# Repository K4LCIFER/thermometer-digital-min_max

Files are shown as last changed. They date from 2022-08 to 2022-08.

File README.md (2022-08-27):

# Digital Min/Max Thermometer

# Introduction

The following project holds all the required files, and information to build a
battery powered digital min/max thermometer.

## Scope

The project is intended to be simple, reliable, and cheap.

## Directory Guide

- [Electronics (PCB, etc.)](./electronics)
- [Hardware (Case, etc.)](./hardware)
- [Firmware](./firmware)

## Donations

Monero (XMR): `8BG1wFgq4fTKhekEh58Ae1M1ShGUsp15yFXJUuCXYQiFKUmDuQ9BK8tTfUfvXV2WR1CPE5Ry6DY45DmdDQm3SiCY7Jkw5ws`
<details><summary>Click to show XMR QR-Code</summary>
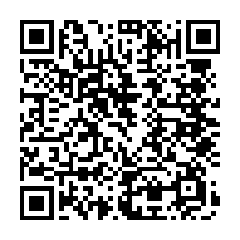
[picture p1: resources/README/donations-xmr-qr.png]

</details>

Bitcoin (BTC): `bc1qvx8jt2qxar7thnxczqalzeyspd0xz8xr046edu`
<details><summary>Click to show BTC QR-Code</summary>
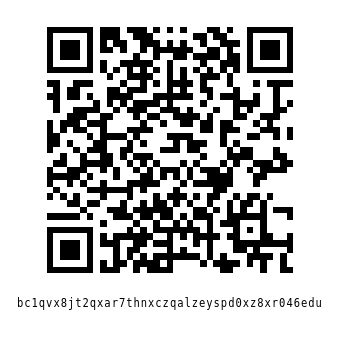
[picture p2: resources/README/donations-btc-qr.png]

</details>

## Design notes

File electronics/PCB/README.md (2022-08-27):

# PCB

## Introduction

This is the directory for the main PCB for the digital min/max thermometer. 

## Directory Map

- [Reference, and manufacturing/assembly information](./resources)
- [Gerber files](./gerbers)
- [PCB Schematic PDFs](./schematics)
- [Files relating to the design software](./project-files)

## Images

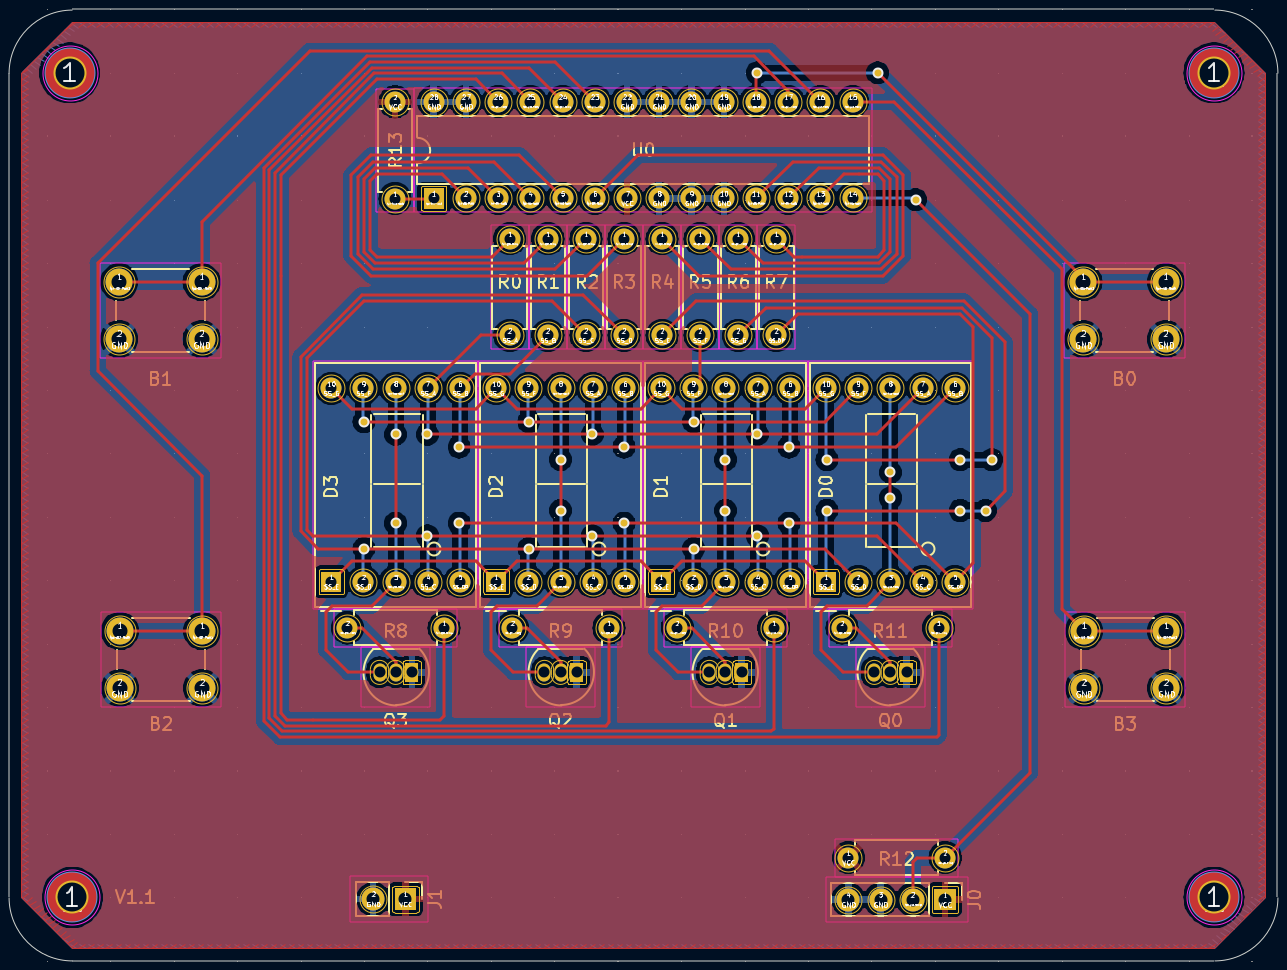
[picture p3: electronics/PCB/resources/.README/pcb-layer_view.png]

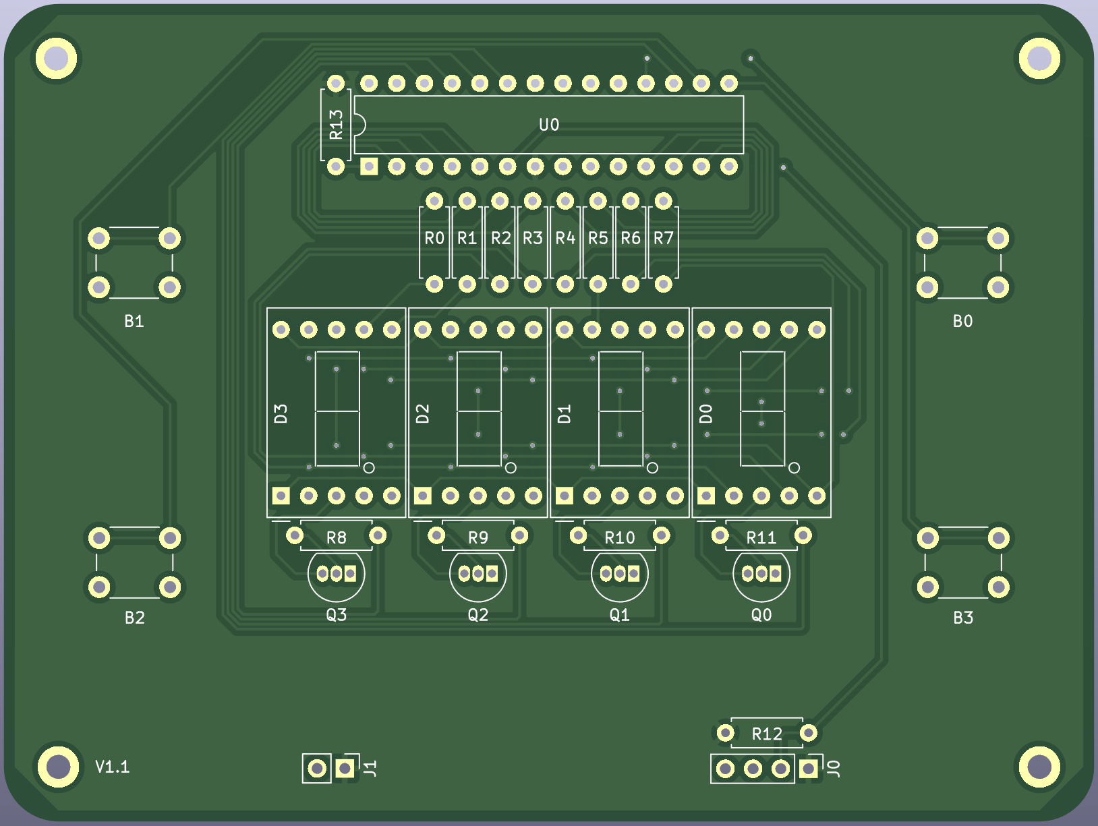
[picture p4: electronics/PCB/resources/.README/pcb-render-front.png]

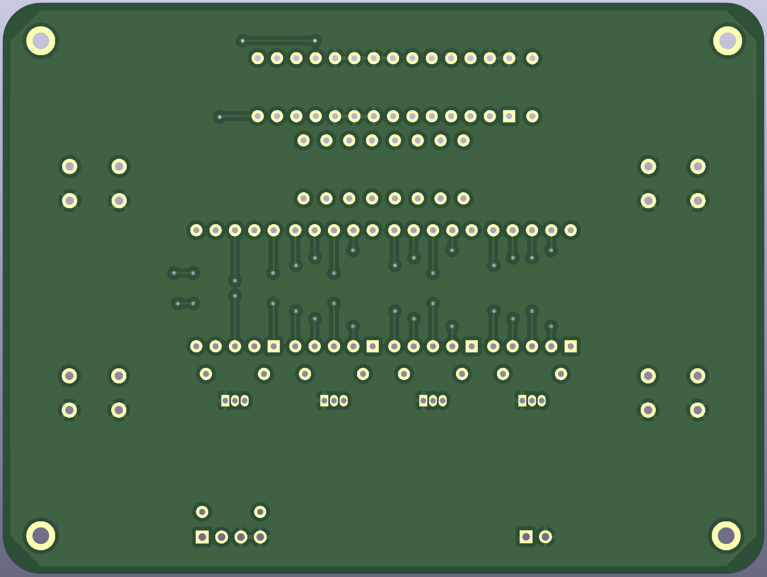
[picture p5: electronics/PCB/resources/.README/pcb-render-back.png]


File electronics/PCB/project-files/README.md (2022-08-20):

This PCB is designed with [KiCAD](https://www.kicad.org/) v6.0.7

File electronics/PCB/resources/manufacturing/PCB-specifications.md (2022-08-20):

# PCB Specifications

These are the physical specifications used for the manufacturing of the PCB.

- Layers: 2
- PCB Thickness:

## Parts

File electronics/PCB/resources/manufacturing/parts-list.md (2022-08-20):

# Parts List
| Part Name | Quantity | Notes |
|---|---|---|
| ATmega328P-U | 1 | | 
| 100R, 0.25W, 1% | 8 | Generic | 
| 10kR, 0.25W, 1% | 1 | Generic |
| 4.7kR, 0.25W, 1% | 1 | Generic |
| 680R, 0.25W, 1% | 4 | Generic |
| INND-TS56RCB | 4 | |
| PN2222A | 4 | |
| 2-Pin Male Header | 1 | Generic |
| 4-Pin Male Header | 1 | Generic |
| 6mm x 6mm Tactile Button | 4 | Generic |

Note: See [this](../datasheets) directory for datasheets on the above components.

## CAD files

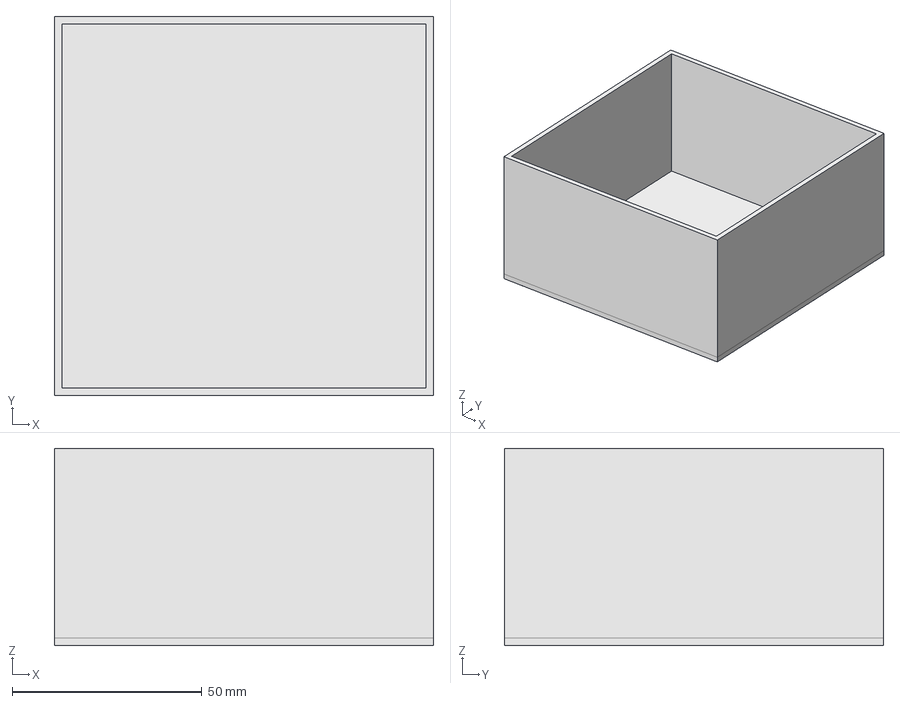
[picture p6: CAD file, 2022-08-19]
hardware/case/project-files/bottom.FCStd
100.0 x 100.0 x 52.0 mm

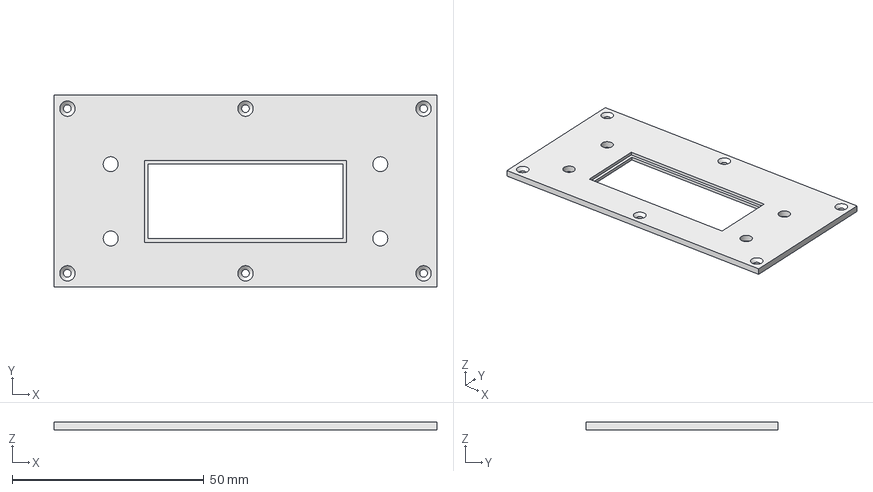
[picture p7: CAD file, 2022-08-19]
hardware/case/project-files/top.FCStd
100.0 x 50.0 x 2.00 mm

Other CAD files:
hardware/case/project-files/global_params.FCStd

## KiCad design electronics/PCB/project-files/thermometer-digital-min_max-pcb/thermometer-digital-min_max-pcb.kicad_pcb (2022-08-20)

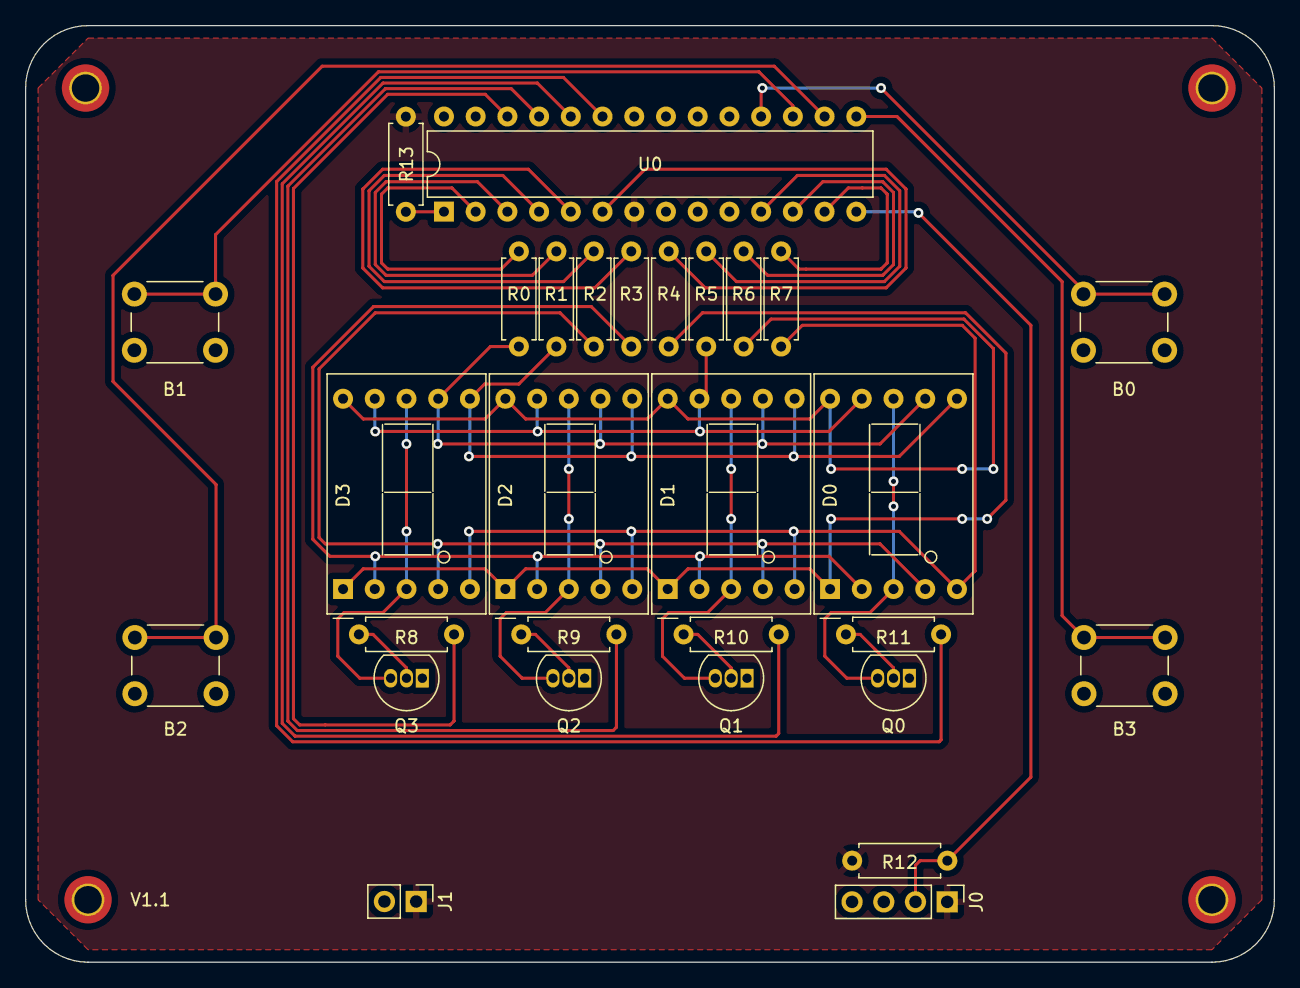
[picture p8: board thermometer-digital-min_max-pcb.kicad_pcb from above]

Board: 2 copper layers, 100.0 x 75.0 mm, 29 parts (0 on the bottom side), 36 nets.

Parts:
B0: disp_current_temp; SW_PUSH_6mm_H9.5mm
B1: disp_max_temp; SW_PUSH_6mm_H9.5mm
B2: disp_min_temp; SW_PUSH_6mm_H9.5mm
B3: reset_saved_temps; SW_PUSH_6mm_H9.5mm
D0, D1, D2, D3: INND-TS56; D1X8K
J0: sensor_connection; PinHeader_1x04_P2.54mm_Vertical
J1: battery_connection; PinHeader_1x02_P2.54mm_Vertical
Q0, Q1, Q2, Q3: PN2222A; TO-92_Inline
R0, R1, R2, R3, R4, R5, R6, R7: 100R; R_Axial_DIN0207_L6.3mm_D2.5mm_P7.62mm_Horizontal
R8, R9, R10, R11: 680R; R_Axial_DIN0207_L6.3mm_D2.5mm_P7.62mm_Horizontal
R12: 4.7k; R_Axial_DIN0207_L6.3mm_D2.5mm_P7.62mm_Horizontal
R13: 10k; R_Axial_DIN0207_L6.3mm_D2.5mm_P7.62mm_Horizontal
U0: ATmega328P-U; DIP-28_W7.62mm

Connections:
/SS_A: D0.7 (A), D1.7 (A), D2.7 (A), D3.7 (A), R0.2
/SS_B: D0.6 (B), D1.6 (B), D2.6 (B), D3.6 (B), R1.2
/SS_C: D0.4 (C), D1.4 (C), D2.4 (C), D3.4 (C), R2.2
/SS_D: D0.2 (D), D1.2 (D), D2.2 (D), D3.2 (D), R3.2
/SS_DP: D0.5 (DP), D1.5 (DP), D2.5 (DP), D3.5 (DP), R7.2
/SS_E: D0.1 (E), D1.1 (E), D2.1 (E), D3.1 (E), R4.2
/SS_F: D0.9 (F), D1.9 (F), D2.9 (F), D3.9 (F), R5.2
/SS_G: D0.10 (G), D1.10 (G), D2.10 (G), D3.10 (G), R6.2
GND: B0.2, B1.2, B2.2, B3.2, J0.3, J0.4, J1.2, Q0.1 (E), Q1.1 (E), Q2.1 (E), Q3.1 (E), U0.8 (GND), U0.9 (XTAL1/PB6), U0.10 (XTAL2/PB7), U0.19 (PB5), U0.20 (AVCC), U0.21 (AREF), U0.22 (GND), U0.27 (PC4), U0.28 (PC5)
unnamed: B0.1, U0.18 (PB4)
unnamed: B1.1, U0.17 (PB3)
unnamed: B2.1, U0.16 (PB2)
unnamed: B3.1, U0.15 (PB1)
unnamed: D0.3 (CC), D0.8 (CC), Q0.3 (C)
unnamed: D1.3 (CC), D1.8 (CC), Q1.3 (C)
unnamed: D2.3 (CC), D2.8 (CC), Q2.3 (C)
unnamed: D3.3 (CC), D3.8 (CC), Q3.3 (C)
unnamed: J0.2, R12.2, U0.14 (PB0)
unnamed: Q0.2 (B), R11.2
unnamed: Q1.2 (B), R10.2
unnamed: Q2.2 (B), R9.2
unnamed: Q3.2 (B), R8.2
unnamed: R0.1, U0.2 (PD0)
unnamed: R1.1, U0.3 (PD1)
unnamed: R2.1, U0.4 (PD2)
unnamed: R3.1, U0.5 (PD3)
unnamed: R4.1, U0.6 (PD4)
unnamed: R5.1, U0.11 (PD5)
unnamed: R6.1, U0.12 (PD6)
unnamed: R7.1, U0.13 (PD7)
unnamed: R8.1, U0.26 (PC3)
unnamed: R9.1, U0.25 (PC2)
unnamed: R10.1, U0.24 (PC1)
unnamed: R11.1, U0.23 (PC0)
unnamed: R13.1, U0.1 (~RESET/PC6)
VCC: J0.1, J1.1, R12.1, R13.2, U0.7 (VCC)

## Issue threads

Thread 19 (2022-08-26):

The mounting hole in the top left corner of the PCB is slightly out of allignment

K4LCIFER, 2022-08-26:
The center of the mounting hole is 4.8mm from the side, and off centered from the top at 87.7deg; It should be 5mm and 90deg for both.

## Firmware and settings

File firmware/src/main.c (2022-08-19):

#define INND_TS56

/* System Defines */
#define F_CPU 8000000UL

/* AVR Includes */
#include <avr/io.h>
#include <avr/interrupt.h>
#include <util/delay.h>
#include <avr/sleep.h>
/* GCC Includes */
#include <string.h>
#include <math.h>
#include <stdlib.h>
/* Library Includes */
#include "seven_segment.h"
#include "atmega328p_utils.h"
/* Program Includes */
#include "am2302_utils.h"
#include "pins.h"
#include "display.h"

// NOTE: Doesn't have to be global, but its currently like this for debugging purposes.
uint16_t temp_data; 

volatile uint16_t ovf_counter = 0;

volatile int current_temp;
volatile int max_temp;
volatile int min_temp;


// NOTE: Should probably disable button interrupts when the sensor is receiving
// to prevent interruption. Don't clear the flag, however, so when they get
// reeneabled, their ISR gets immediately called.
void init(void);
uint8_t get_temp(void);
void display_temp(uint16_t temp_data);
void process_buttons(void);

void main(void)
{
    init();
    // Clear the Timer 2 OVF interrupt flag.
    TIFR2 |= (1 << TOV2);
    // Enable the Timer 2 OVF interrupt.
    TIMSK2 |= (1 << TOIE2);
    // Start Timer 2 with CLK/1024.
    TCCR2B |= ((1 << CS22) | (1 << CS21) | (1 << CS20));
    while(1)
    {
        if (ovf_counter >= 100)
        {
            PCICR &= ~(1 << PCIE0); // Disable pushbutton interrupts.
            ovf_counter = 0;
            get_temp();
            if (current_temp > max_temp)
            {
                max_temp = current_temp;
            }
            if (current_temp < min_temp)
            {
                min_temp = current_temp;
            }
            PCICR |= (1 << PCIE0); // Enable pushbutton interrupts.
        }
    }
}

void init(void)
{

    // Reduce power consumption:
    PRR |= (1 << PRADC);    // Disables the ADC.
    PRR |= (1 << PRUSART0); // Disables the USART0
    PRR |= (1 << PRSPI);    // Disables the SPI
/*     PRR |= (1 << PRTIM0);   // Disables the Timer0 */
    PRR |= (1 << PRTWI);    // Disables the TWI
    SMCR |= ((1 << SM1) | (1 << SM0));  // Power save mode
    SMCR |= (1 << SE);  // Enable sleep.
    sleep_bod_disable();    // Disable BOD.

    // Configure the buttons:
    // Set the button pins as inputs, and enable their pull-ups:
    // Reset saved temperatures button.
    pin_config_input(reset_saved_temps_btn_pin);
    pin_pullup_enable(reset_saved_temps_btn_pin);
    // Display minimum temperature button.
    pin_config_input(disp_min_temp_btn_pin);
    pin_pullup_enable(disp_min_temp_btn_pin);
    // Display maximum temperature button.
    pin_config_input(disp_max_temp_btn_pin);
    pin_pullup_enable(disp_max_temp_btn_pin);
    // Display current temperature button.
    pin_config_input(disp_current_temp_btn_pin);
    pin_pullup_enable(disp_current_temp_btn_pin);

    sensor_init();
    display_init();


    sei();  // Enable global interrupts.

    // Initialize values:
    get_temp();
    max_temp = current_temp;
    min_temp = current_temp;

    // Set up the interrupts for hte buttons:
    // Enable interrupts for the 4 pushbuttons on their respective pins.
    PCMSK0 |= ((1 << PCINT1) | (1 << PCINT2) | (1 << PCINT3) | (1 << PCINT4));
    PCIFR |= (1 << PCIF0); // Ensure that the button interrupt is cleared.
    PCICR |= (1 << PCIE0); // Enable pushbutton interrupts.

    DDRB |= (1 << DDB7); // Test LED.
}


uint8_t get_temp(void)
{
    sensor_rx(sensor_data_pin);    // Retreive data from the sensor.
    
    // Extract the temperature digits.
    /*uint16_t*/ temp_data = (raw_sensor_data & TEMP_DATA_BITMASK) 
        >> TEMP_DATA_OFFSET;
    current_temp = 1;   // Allows for easy multiplication.
    
    // Check if there if the negative temperature flag is set:
    if (raw_sensor_data & NEG_TEMP_BITMASK)
    {
        current_temp *= -1; // Floating point value of the temperature.
    }
    // Udate the current temperature value.
    current_temp *= temp_data;
    
    return 0;
}

// TODO: Add the a timer overflow catcher in case of a failed transmission.

// ISR for buttons:
ISR (PCINT0_vect)
{
    // Stop the temperature retreival timer.
    TCCR2B &= ~((1 << CS22) | (1 << CS21) | (1 << CS20));
    if (!pin_get_input_value(disp_current_temp_btn_pin))
    {
        if (current_temp < 0)
        {
            display_buffer[0] = SS_NEG;
        }
        for (uint8_t i = 0; i < 3; i++)
        {
            // Extract the digit.
            display_buffer[i] = ss_display_table[
                abs(current_temp / (int)pow(10,i)) % 10
            ];
        }
        display_buffer[1] |= SS_DEC;
        // Enable the display
        display_enable();
        // Reset the timer.
        TCNT1 = 0;
        // Clear the compare match A interrupt flag.
        TIFR1 |= (1 << OCF1A);
        // Interrupt on compare match.
        TIMSK1 |= (1 << OCIE1A);
        // Compare match at 5s (~39063 cycles)
        OCR1A = 39063; // 5s * (8MHz / 1024)
        // Enable the timer with CLK/1024
        TCCR1B |= ((1 << CS12) | (1 << CS10));
    }
    else if (!pin_get_input_value(disp_max_temp_btn_pin))
    {
        if (max_temp < 0)
        {
            display_buffer[0] = SS_NEG;
        }
        for (uint8_t i = 0; i < 3; i++)
        {
            // Extract the digit.
            display_buffer[i] = ss_display_table[
                abs(max_temp / (int)pow(10,i)) % 10
            ];
        }
        display_buffer[1] |= SS_DEC;
        // Enable the display
        display_enable();
        // Reset the timer.
        TCNT1 = 0;
        // Clear the compare match A interrupt flag.
        TIFR1 |= (1 << OCF1A);
        // Interrupt on compare match.
        TIMSK1 |= (1 << OCIE1A);
        // Compare match at 5s (~39063 cycles)
        OCR1A = 39063; // 5s * (8MHz / 1024)
        // Enable the timer with CLK/1024
        TCCR1B |= ((1 << CS12) | (1 << CS10));
    }
    else if (!pin_get_input_value(disp_min_temp_btn_pin))
    {
        if (min_temp < 0)
        {
            display_buffer[0] = SS_NEG;
        }
        for (uint8_t i = 0; i < 3; i++)
        {
            // Extract the digit.
            display_buffer[i] = ss_display_table[
                abs(min_temp / (int)pow(10,i)) % 10
            ];
        }
        display_buffer[1] |= SS_DEC;
        // Enable the display
        display_enable();
        // Reset the timer.
        TCNT1 = 0;
        // Clear the compare match A interrupt flag.
        TIFR1 |= (1 << OCF1A);
        // Interrupt on compare match.
        TIMSK1 |= (1 << OCIE1A);
        // Compare match at 5s (~39063 cycles)
        OCR1A = 39063; // 5s * (8MHz / 1024)
        // Enable the timer with CLK/1024
        TCCR1B |= ((1 << CS12) | (1 << CS10));
    }
    else if (!pin_get_input_value(reset_saved_temps_btn_pin))
    {
        max_temp = current_temp;
        min_temp = current_temp;
    }
}

// Display timeout ISR. (Turns off the display after 5s).
ISR (TIMER1_COMPA_vect)
{
    // Turn off the display.
    display_disable();
    // Stop the timer.
    TCCR1B &= ~((1 << CS12) | (1 << CS11) | (1 << CS10));
    // Disable the timer interrupts.
    TIMSK1 &= ~(1 << OCIE1A);
    // Restart the temperature retreival timer.
    TCCR2B |= ((1 << CS22) | (1 << CS21) | (1 << CS20));
}

ISR (TIMER2_OVF_vect)
{
    ovf_counter++;
}

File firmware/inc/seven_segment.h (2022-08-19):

////////////////////////////////////////////////////////////////////////////////
// To use this header file, make sure that you define the name/series of the 
// 7 segment display that you will be using in your program code where this 
// header file is included.
////////////////////////////////////////////////////////////////////////////////

#ifndef _SEVEN_SEGMENT_H_
#define _SEVEN_SEGMENT_H_

#ifdef INND_TS56
//      SEVEN_SEGMENT_<X>   0b<DP><G><F><E><D><C><B><A>
#define _SS_A   0b00000001
#define _SS_B   0b00000010
#define _SS_C   0b00000100
#define _SS_D   0b00001000
#define _SS_E   0b00010000
#define _SS_F   0b00100000
#define _SS_G   0b01000000
#define _SS_DP  0b10000000

#define SS_0    _SS_A | _SS_B | _SS_C | _SS_D | _SS_E | _SS_F
#define SS_1    _SS_B | _SS_C
#define SS_2    _SS_A | _SS_B | _SS_G | _SS_E | _SS_D
#define SS_3    _SS_A | _SS_B | _SS_G | _SS_C | _SS_D
#define SS_4    _SS_F | _SS_G | _SS_B | _SS_C
#define SS_5    _SS_A | _SS_F | _SS_G | _SS_C | _SS_D
#define SS_6    _SS_A | _SS_F | _SS_G | _SS_C | _SS_D | _SS_E
#define SS_7    _SS_A | _SS_B | _SS_C
#define SS_8    _SS_A | _SS_B | _SS_C | _SS_D | _SS_E | _SS_F \
    | _SS_G
#define SS_9    _SS_A | _SS_F | _SS_B | _SS_G | _SS_C
#define SS_DEC  _SS_DP
#define SS_NEG  _SS_G
#define SS_CLEAR    0
#endif

#endif

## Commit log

2022-08-19 fixed a syntax error.
    [main.c]
2022-08-19 Still trying to fix the sensor data issues
    [main.c]
2022-08-19 Got the data communication working. Issues with interrupt flags, compiler optimizations not being enabled, and many other minor bugs.
    [main.c]
2022-08-19 - Rewrote the receive function, and the related interrupt routine(s). - I switched away from timing the high of the bit, to just capturing the entire bit period. - Added a checksum routine for the re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
2022-08-19 Fixed a bunch of warnings.
    [main.c]
2022-08-19 Started the PCB
    [thermometer-min_max-digital-pcb.kicad_pcb, thermometer-min_max-digital-pcb.kicad_sch]
2022-08-19 v1.0 of PCB
    [thermometer-digital-min_max-pcb-B_Cu.gbr, thermometer-digital-min_max-pcb-B_Mask.gbr, thermometer-digital-min_max-pcb-B_Paste.gbr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]
2022-08-19 just commiting everything to clean up git. some firmware stuff was accidentally written while in the pcb branch. I'm too lazy to clean up the commits, so I'm just going to start from square one by co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
    [bottom.FCStd, global_params.FCStd, top.FCStd]
2022-08-19 refactored the file tree by moving the PCB files into the new electronics folder in the root directory.
    [thermometer-digital-min_max-pcb-B_Cu.gbr, thermometer-digital-min_max-pcb-B_Mask.gbr, thermometer-digital-min_max-pcb-B_Paste.gbr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]
2022-08-19 Testing signing
    [thermometer-digital-min_max-pcb.kicad_pcb, thermometer-digital-min_max-pcb.kicad_sch]
2022-08-19 Completed the relayout of the PCB
    [thermometer-digital-min_max-pcb.kicad_pcb]
2022-08-19 Updated gerber files to match the new layout.
    [thermometer-digital-min_max-pcb-B_Cu.gbr, thermometer-digital-min_max-pcb-B_Mask.gbr, thermometer-digital-min_max-pcb-B_Paste.gbr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]
2022-08-19 Adjusted the position of the silkscreen for some components
    [thermometer-digital-min_max-pcb.kicad_pcb]
2022-08-20 Refactoring and documentation (#16)
    Added many starting point documentation files, and added documentation for the pcb, and firmware. Refactored some of the source tree so that it makes a bit more logical sense.
2022-08-20 Added a link to the KiCAD website in the KiCAD project files README
2022-08-20 Updated gerbers
    [thermometer-digital-min_max-pcb-B_Cu.gbr, thermometer-digital-min_max-pcb-B_Mask.gbr, thermometer-digital-min_max-pcb-B_Paste.gbr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]
2022-08-20 Updated PCB to v1.1
    [thermometer-digital-min_max-pcb-B_Cu.gbr, thermometer-digital-min_max-pcb-B_Mask.gbr, thermometer-digital-min_max-pcb-B_Paste.gbr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]
2022-08-20 Fixed gerbers. There were leftover layers from previous 4 layer.
    [thermometer-digital-min_max-pcb-B_Cu.gbr, thermometer-digital-min_max-pcb-B_Mask.gbr, thermometer-digital-min_max-pcb-B_Paste.gbr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]
2022-08-27 Added PCB pictures to the PCB README (#20)
    Also added a folder for README resources relative to PCB: ./resouces/./README/*
